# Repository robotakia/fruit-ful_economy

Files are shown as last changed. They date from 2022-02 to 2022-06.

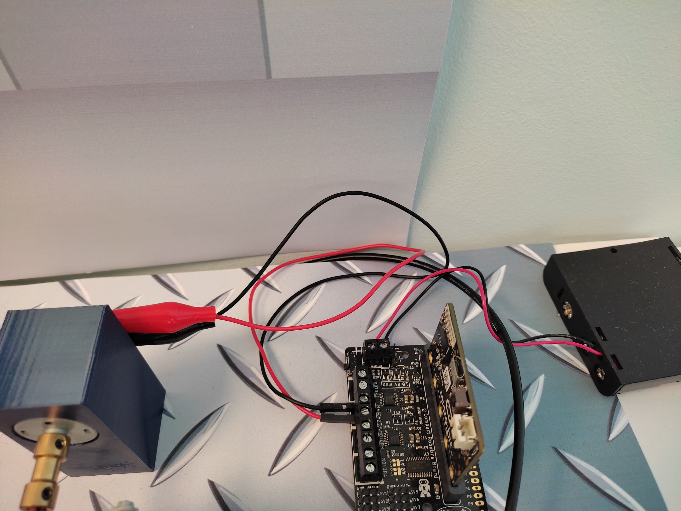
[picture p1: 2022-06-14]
02_Συνδεσμολογία/dc_motor1.jpg

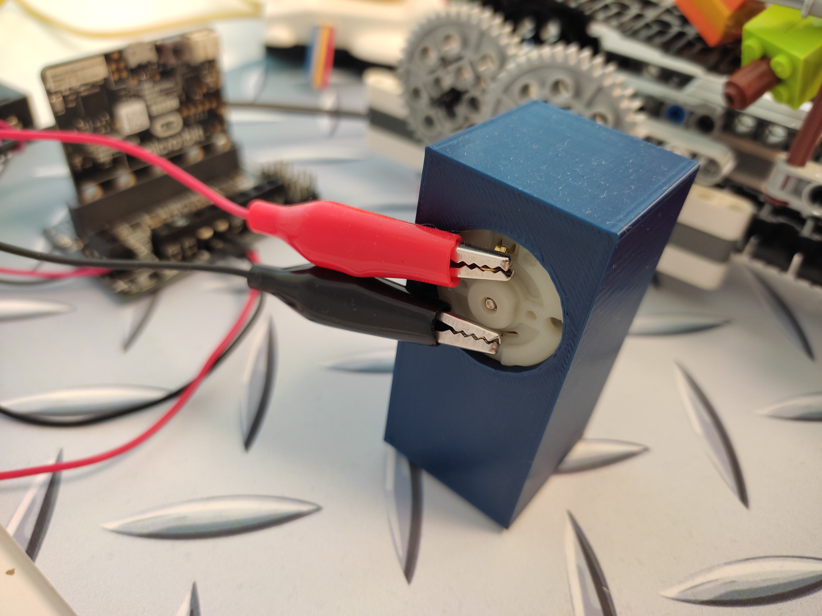
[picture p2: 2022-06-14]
02_Συνδεσμολογία/dc_motor2.jpg

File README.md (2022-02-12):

# fruit-ful_economy

Θα φτιαχτεί μια μακέτα στην οποία θα πραγματοποιείται ο διαχωρισμός οργανικών απορριμμάτων.  

Στο project θα περιλαμβάνονται τα εξής: 

-Ένας ιμάντας στον οποίο θα κινούνται τα τρόφιμα (υπολείμματα φρούτων ή και ολόκληρα φρούτα τα οποία είναι πχ χτυπημένα και δεν είναι κατάλληλα για κατανάλωση) 

-Μια κάμερα η οποία θα αναγνωρίζει τα φρούτα χάρη σε μοντέλο που θα έχουμε κάνει training 

-Ένας ρομποτικός βραχίονας που θα τα ξεχωρίζει ώστε τα πορτοκάλια να σταλθούν για δημιουργία υφασμάτων και τα υπόλοιπα για κομποστοποίηση

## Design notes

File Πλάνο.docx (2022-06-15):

# Πλάνο

Στην 1^η μας συνάντηση συζητήσαμε το θέμα του διαγωνισμού και αναζητήσαμε πληροφορίες στο διαδίκτυο. Κάθε μαθητής πρότεινε από μια ιδέα και στην συνέχεια ψάξαμε τρόπους να ενώσουμε αυτές τις ιδέες. Κάποιες από τις ιδέες για την κατασκευή προήλθαν από πράγματα που είχαν ήδη δει τα παιδιά στα εργαστήρια που παρακολουθούν στους ετήσιους κύκλους όπως το να εκπαιδεύσουμε ένα μοντέλο αναγνώρισης αντικειμένων ή να φτιάξουμε ένα βραχίονα.

Στην 2^η συνάντηση ξεκινήσαμε να φτιάχνουμε τον ιμάντα και ψάξαμε τρόπους να κάνουμε συμβατό τον DC κινητήρα με κομμάτια Lego. Βρήκαμε λοιπόν ένα εξάρτημα που λέγεται shaft coupler. Αυτό το εξάρτημα μοιάζει σαν τουνελ με τη διαφορά ότι η μια πλευρά από την άλλη μπορεί να έχει διαφορετικό μέγεθος. Το δικό μας shaft coupler από την μια μεριά ήταν 2mm για να μπαίνει ο κινητήρας και από την άλλη πλευρά 5mm για να μπαίνει ο άξονας

(εικόνα 1)

Προβληματιστήκαμε για την ενέργεια που θα χρειαστεί ο κινητήρας ώστε να λειτουργήσει σωστά με το microbit και γι’ αυτό χρησιμοποιήσαμε το Robotics board και μια μπαταριοθήκη

(εικόνα 2)

Στην 3^η συνάντηση συνδέσαμε τον κινητήρα στον ιμάντα με το shaft coupler αλλά και με το board και τον προγραμματίσαμε με τη γλώσσα Microsoft Make code. Μιας και το μόνο που μας ενδιέφερε ήταν ο ιμάντας να κινείται ασταμάτητα το μόνο που έπρεπε να κάνουμε ήταν να βρούμε την κατάλληλη επέκταση εντολών.

Για να το κάνουμε αυτό μπήκαμε στην σελίδα

https://makecode.microbit.org/#editor

Πατήσαμε για προχωρημένους

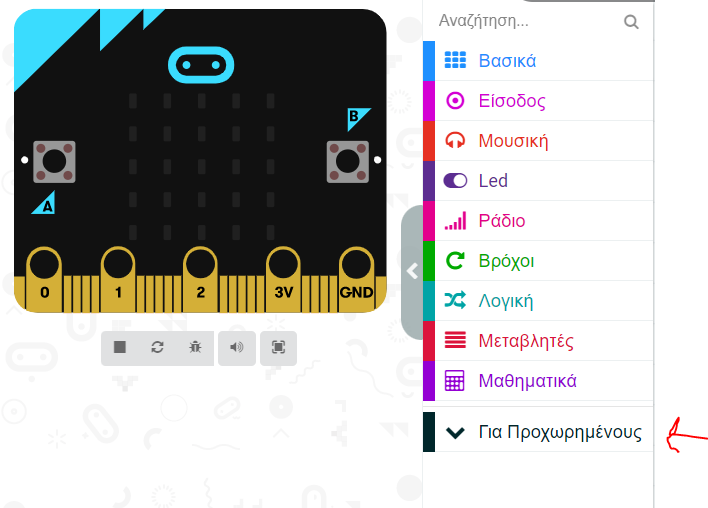
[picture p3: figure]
Εικόνα που περιέχει κείμενο Περιγραφή που δημιουργήθηκε αυτόματα

Επεκτάσεις

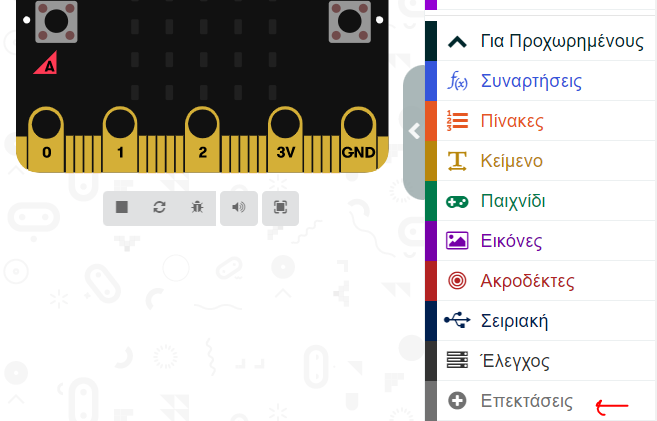
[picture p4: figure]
Εικόνα που περιέχει κείμενο Περιγραφή που δημιουργήθηκε αυτόματα

Και στην αναζήτηση πληκτρολογήσαμε kitronik robotics board

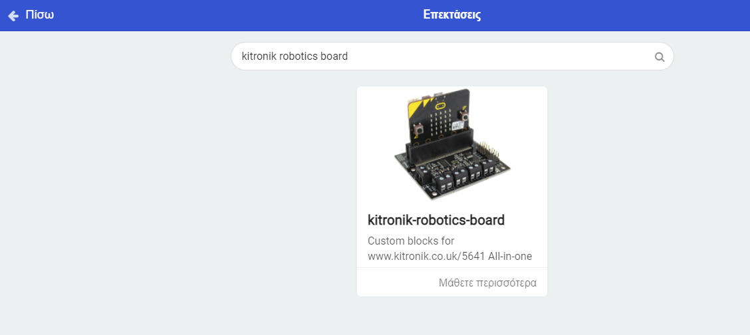
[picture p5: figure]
Εικόνα που περιέχει κείμενο Περιγραφή που δημιουργήθηκε αυτόματα

Αφού το επιλέξουμε εμφανίζεται στις ήδη υπάρχουσες κατηγορίες εντολών μια νέα, η Robotics

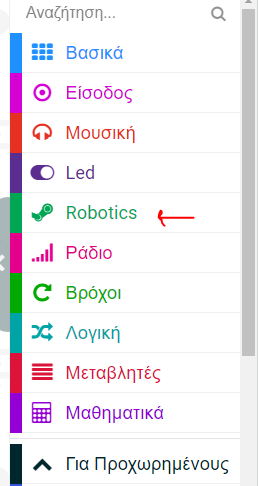
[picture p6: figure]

Σε μια επανάληψη (για πάντα) βάζουμε την εντολή που ορίζει την κατεύθυνση και την ταχύτητα του κινητήρα. Υπάρχουν εντολές για διάφορα ήδη κινητήρων (stepper, servo) όμως εμάς μας ενδιαφέρει η Motors

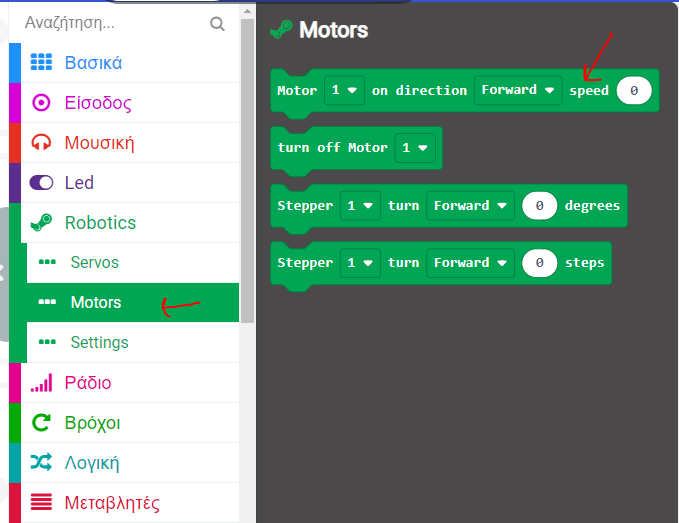
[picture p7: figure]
Εικόνα που περιέχει κείμενο Περιγραφή που δημιουργήθηκε αυτόματα

Σημαντικό είναι να δούμε στο board σε ποιο Motor (1 ή 2) έχουμε συνδέσει τον κινητήρα και με δοκιμές να βρούμε την κατάλληλη ισχύ ώστε ο ιμάντας να κινείται όπως επιθυμούμε

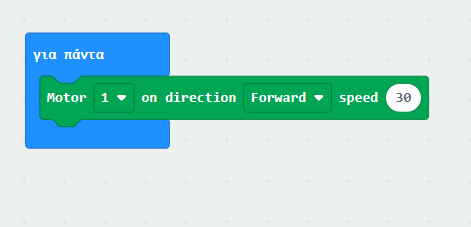
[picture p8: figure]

Στην 4^η συνάντηση αναζητήσαμε στο διαδίκτυο τις κατάλληλες για εμάς εικόνες για φόντο και δάπεδο της μακέτας μας και σχεδιάσαμε μέσω της σελίδας https://www.tinkercad.com

μια βάση για τον κινητήρα μας ώστε να βρίσκεται στο κατάλληλο ύψος, μια βάση για τον κινητήρα servo που θα γύριζε το βραχίονα αλλά και τον ίδιο το βραχίονα. Πήραμε μετρήσεις (πχ σε πόσο ύψος πρέπει να βρίσκεται ο κινητήρας, πόση διάμετρο έχει), πειραματιστήκαμε και τυπώσαμε αρκετά σχέδια ώσπου να καταλήξουμε σε αυτά που τελικά λειτούργησαν για εμάς.

Στην 5^η και τελευταία μας συνάντηση εκπαιδεύσαμε το μοντέλο μας (οδηγίες βρίσκονται στο github στον φάκελο 1. Pre-trained model) και προγραμματίσαμε το βραχίονα μέσω της σελίδας https://stretch3.github.io/ η οποία είναι παρόμοια με τη γλώσσα scratch. Χρειάστηκε να προσθέσουμε τις επεκτάσεις

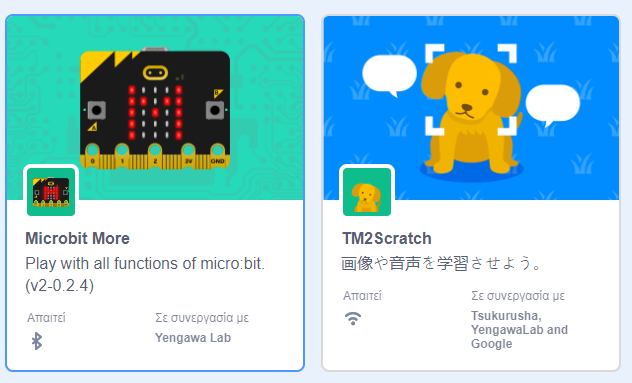
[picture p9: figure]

ώστε να έχουμε στη διάθεση μας τις εντολές για να συνδέσουμε το πρόγραμμα μας με το μοντέλο που εκπαιδεύσαμε αλλά και για να προγραμματίσουμε τον servo που συνδέσαμε στο microbit sensor shield

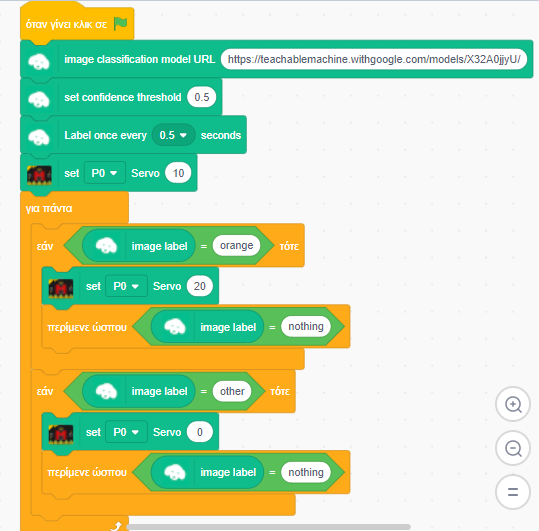
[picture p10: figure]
Εικόνα που περιέχει κείμενο Περιγραφή που δημιουργήθηκε αυτόματα

Όταν πατάμε την πράσινη σημαία για να αρχίσει το πρόγραμμα, χρησιμοποιεί το link από το μοντέλο που εκπαιδεύσαμε και κάθε 0,5 δευτερόλεπτο πραγματοποιεί έλεγχο αν κάτι έχει αλλάξει σε σχέση με αυτό που εμφανίζεται στην κάμερα. Αρχικοποιούμε τον κινητήρα servo και στην συνέχεια ελέγχουμε τι είναι αυτό που εμφανίζεται μπροστά στην κάμερα. Αν δει πορτοκάλι (που είναι το φρούτο που μας ενδιαφέρει) γυρίζει τον κινητήρα στις 20 μοίρες και τον διατηρεί σε αυτή τη θέση ώσπου το φρούτο να φύγει από το οπτικό πεδίο της κάμερας. Το ίδιο κάνουμε και για τα υπόλοιπα φρούτα (εμείς δοκιμάσαμε πράσινο μήλο και αχλάδι).

Στο GitHub βρίσκονται τα αρχεία των 3D σχεδίων, τα αρχεία των προγραμμάτων, η λίστα των υλικών καθώς και οδηγίες για το πώς να εκπαιδεύσουμε το μοντέλο.

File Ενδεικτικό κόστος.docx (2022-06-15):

# Ενδεικτικό κόστος

2 x microbit (44 ευρώ)

1 x Keyestudio sensor shield για microbit (6,5 ευρώ)

1 x usb camera (10 ευρώ)

1 x Kitronik Compact all in one robotics board για microbit (15 ευρώ)

1 x 12 V DC motor (2,40 ευρώ)

1 x shaft coupler 2mm- 5mm (1,45 ευρώ)

Αφίσες (φόντο- δάπεδο) (15 ευρώ)

Lego για διάδρομο (περίπου 10 ευρώ)

2 x alligator clips- male (1 ευρώ)

1 x θήκη για μπαταρίες με καλώδια (1,20 ευρώ)

Συνολικό κόστος: Περίπου 106,55

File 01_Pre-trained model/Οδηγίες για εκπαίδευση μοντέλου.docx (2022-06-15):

# Οδηγίες για εκπαίδευση μοντέλου

Πηγαίνουμε στην σελίδα

https://teachablemachine.withgoogle.com/

και πατάμε Get started

Επιλέγουμε Image Project

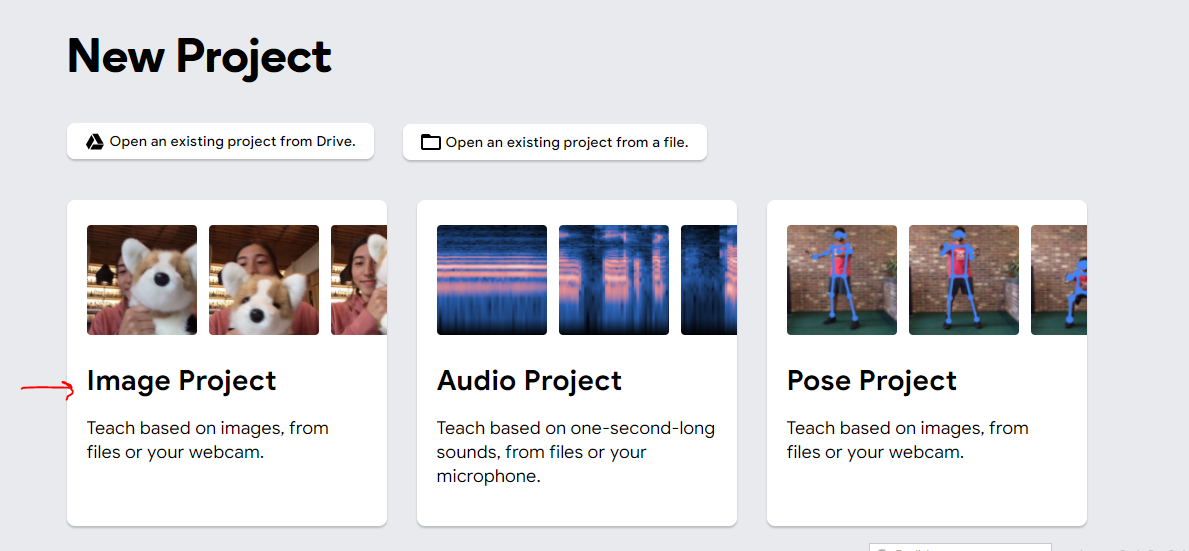
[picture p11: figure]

Στην συνέχεια Standard Image Model

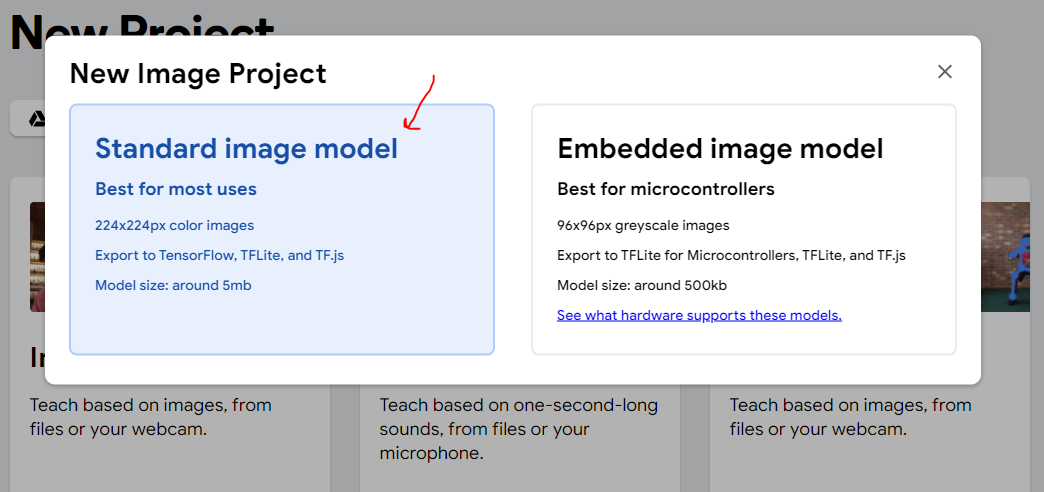
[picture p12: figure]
Εικόνα που περιέχει κείμενο Περιγραφή που δημιουργήθηκε αυτόματα

Στα Class1, Class2 κοκ συμπληρώνουμε nothing, orange και δημιουργούμε ένα ακόμα συμπληρώνοντας other.

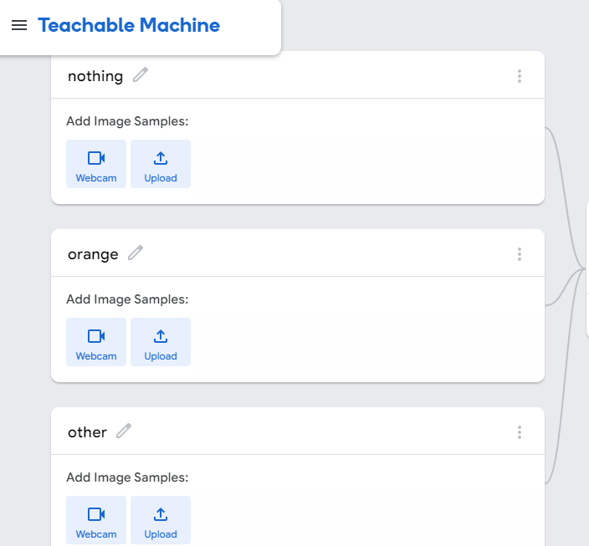
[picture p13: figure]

Σε κάθε ένα από αυτά πατάμε webcam και στην συνέχεια έχοντας πατημένο το Hold to record τραβάμε φωτογραφίες. Στο nothing τραβάμε φωτογραφίες μόνο της κατασκευής ενώ στις άλλες δύο κατηγορίες τραβάμε φωτογραφίες των αντίστοιχων φρούτων πάνω στο διάδρομο, σε διάφορες θέσεις

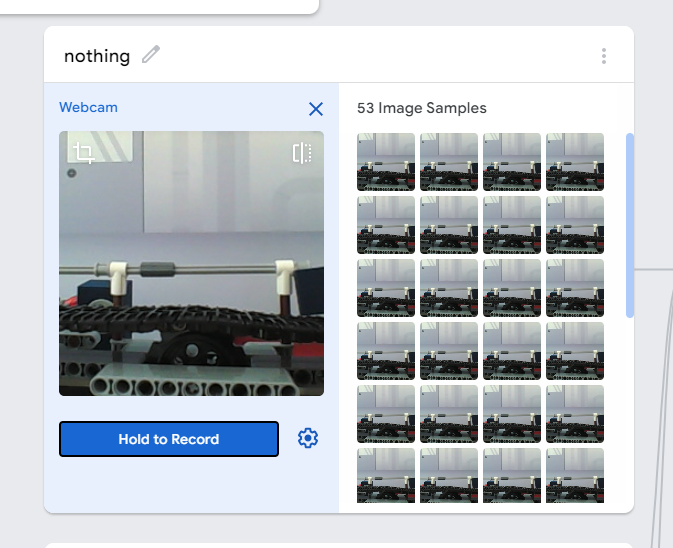
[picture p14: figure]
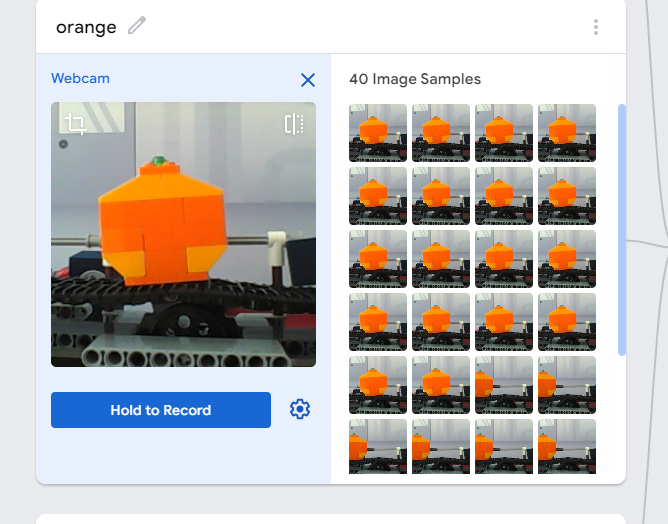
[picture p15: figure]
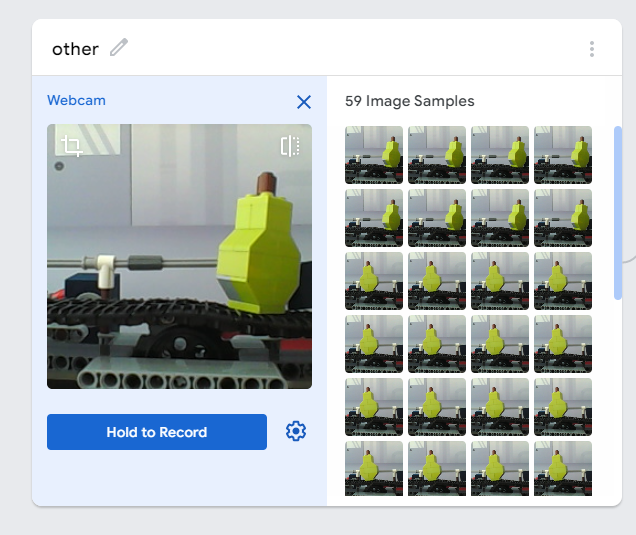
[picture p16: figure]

Στην συνέχεια επιλέγουμε Train Model

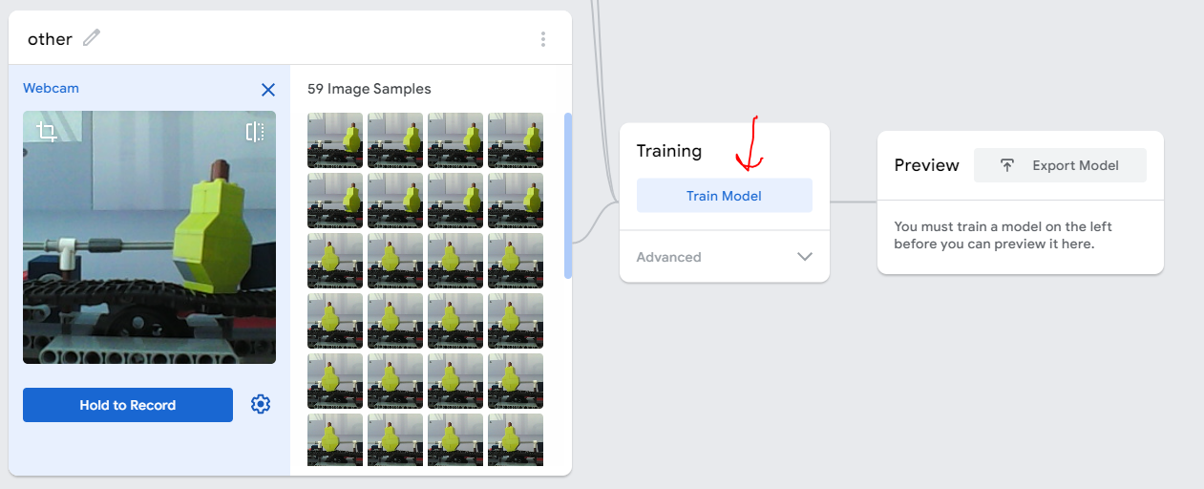
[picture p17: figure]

Μόλις τελειώσει την επεξεργασία πατάμε Export Model

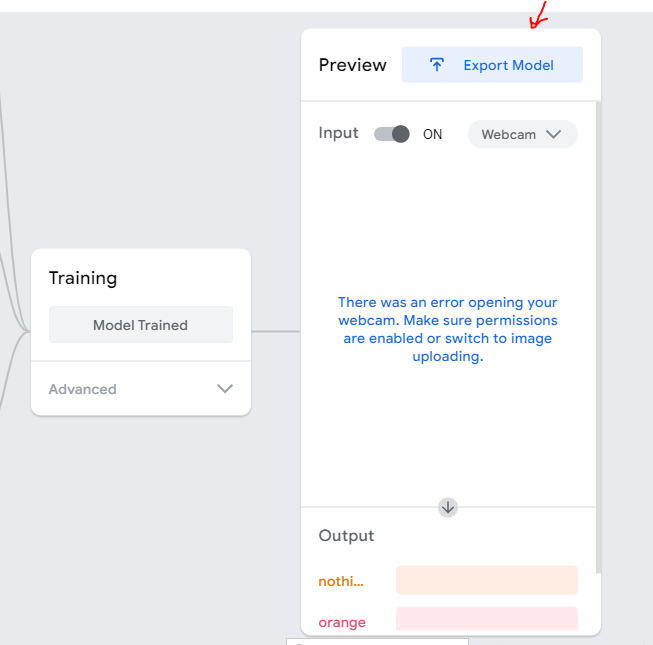
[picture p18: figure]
Εικόνα που περιέχει κείμενο Περιγραφή που δημιουργήθηκε αυτόματα

Έπειτα Upload my model

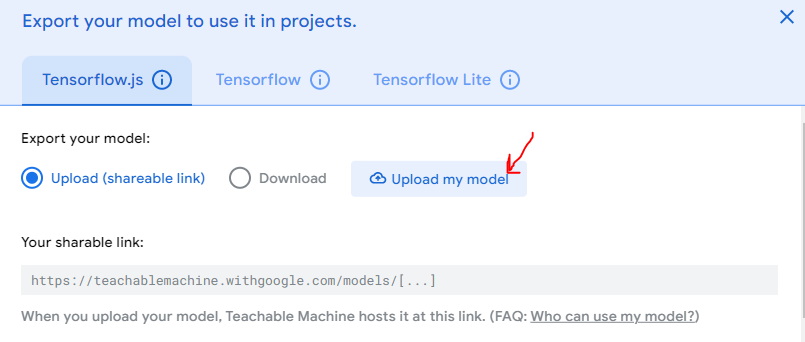
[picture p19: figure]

Και παίρνουμε το link και το αποθηκεύουμε σε ένα txt αρχείο για να το χρησιμοποιήσουμε αργότερα στο πρόγραμμα μας

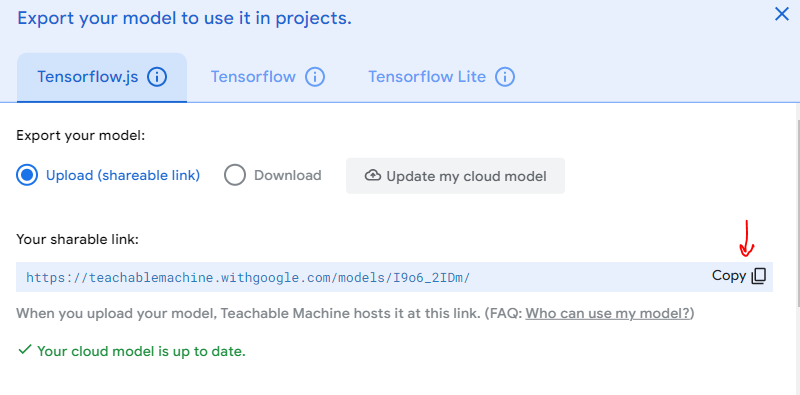
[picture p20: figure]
Εικόνα που περιέχει κείμενο Περιγραφή που δημιουργήθηκε αυτόματα

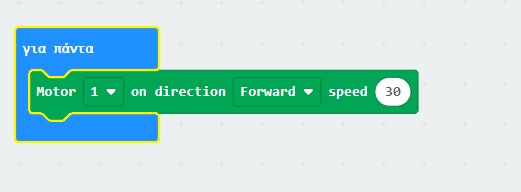
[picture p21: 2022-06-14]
04_Προγραμματισμός/motor.PNG

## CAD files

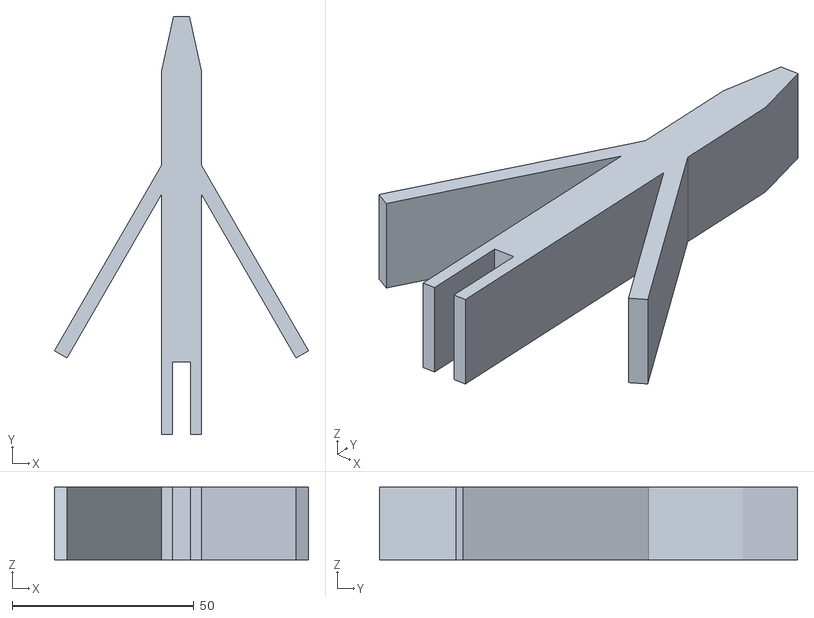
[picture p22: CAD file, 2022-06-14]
03_3D Printing/arm 1.stl
69.9 x 115.0 x 20.0

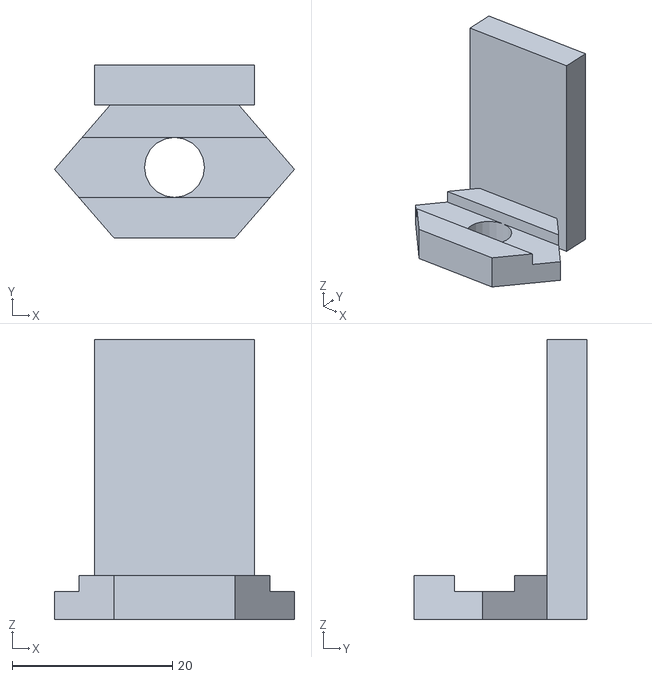
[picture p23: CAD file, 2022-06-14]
03_3D Printing/arm 2.stl
30.0 x 21.6 x 35.0

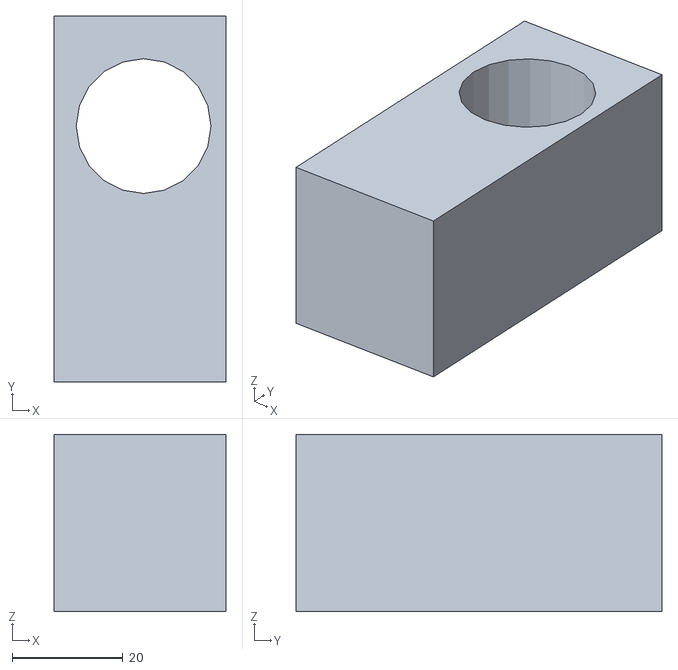
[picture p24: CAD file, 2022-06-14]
03_3D Printing/motor_base.stl
31.0 x 66.0 x 32.0
